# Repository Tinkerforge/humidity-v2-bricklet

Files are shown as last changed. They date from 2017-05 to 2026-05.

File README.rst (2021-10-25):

Humidity Bricklet 2.0
=====================

This repository contains the firmware source code and the hardware design
files. The documentation generator configs can be found at
https://github.com/Tinkerforge/generators

Repository Content
------------------

software/:
 * examples/: Examples for all supported languages
 * build/: Compiled files
 * src/: Source code of firmware
 * Makefile: Makefile to build project

hardware/:
 * Contains KiCad project files and additionally schematics as PDF

datasheets/:
 * Contains datasheets for sensors and complex ICs that are used

Hardware
--------

The hardware is designed with the open source EDA Suite KiCad
(http://www.kicad.org). Before you are able to open the files,
you have to install the Tinkerforge kicad-libraries
(https://github.com/Tinkerforge/kicad-libraries). You can either clone
them directly in hardware/ or clone them in a separate folder and
symlink them into hardware/
(ln -s kicad_path/kicad-libraries project_path/hardware). After that you
can open the .pro file in hardware/ with KiCad and from there view and
modify the schematics and the PCB layout.

Software
--------

If you want to do your own Brick/Bricklet firmware development we highly
recommend that you use our build environment setup script and read the
tutorial (https://www.tinkerforge.com/en/doc/Tutorials/Tutorial_Build_Environment/Tutorial.html).

To compile the C code we recommend you to install the newest GNU Arm Embedded
Toolchain (https://launchpad.net/gcc-arm-embedded/+download).
You also need to install bricklib2 (https://github.com/Tinkerforge/bricklib2).

You can either clone it directly in software/src/ or clone it in a
separate folder and symlink it into software/src/
(ln -s bricklib_path/bricklib2 project_path/software/src/). Finally make sure to
have CMake installed (http://www.cmake.org/cmake/resources/software.html).

After that you can build the firmware by invoking make in software/.
The firmware (.zbin) can then be found in software/build/ and uploaded
with brickv (click button "Flashing" on start screen).

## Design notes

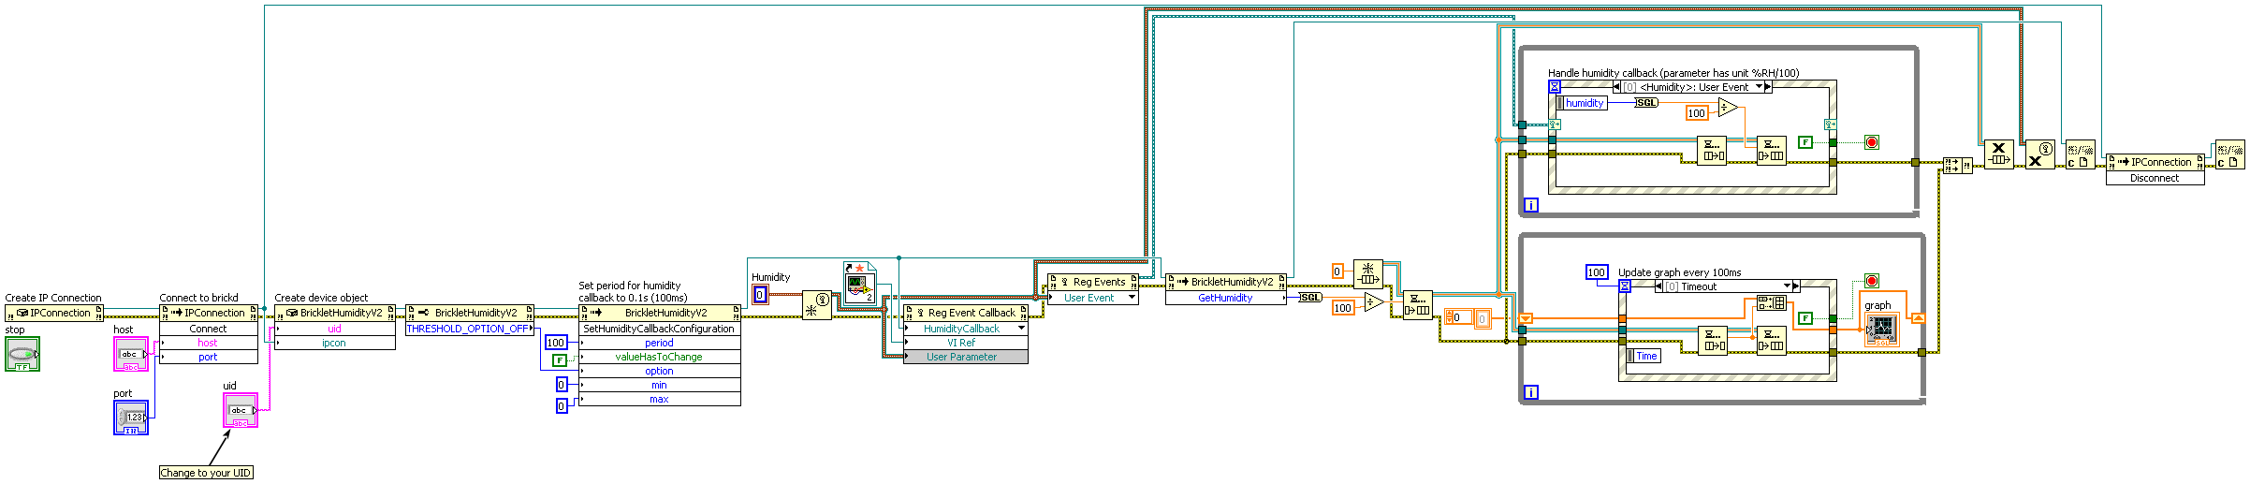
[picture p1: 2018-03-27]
software/examples/labview/Example Graph.vi.png

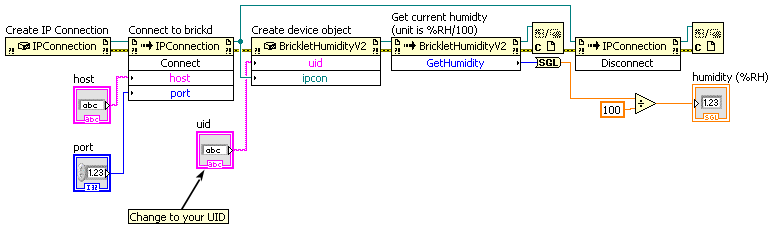
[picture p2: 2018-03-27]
software/examples/labview/Example Simple.vi.png

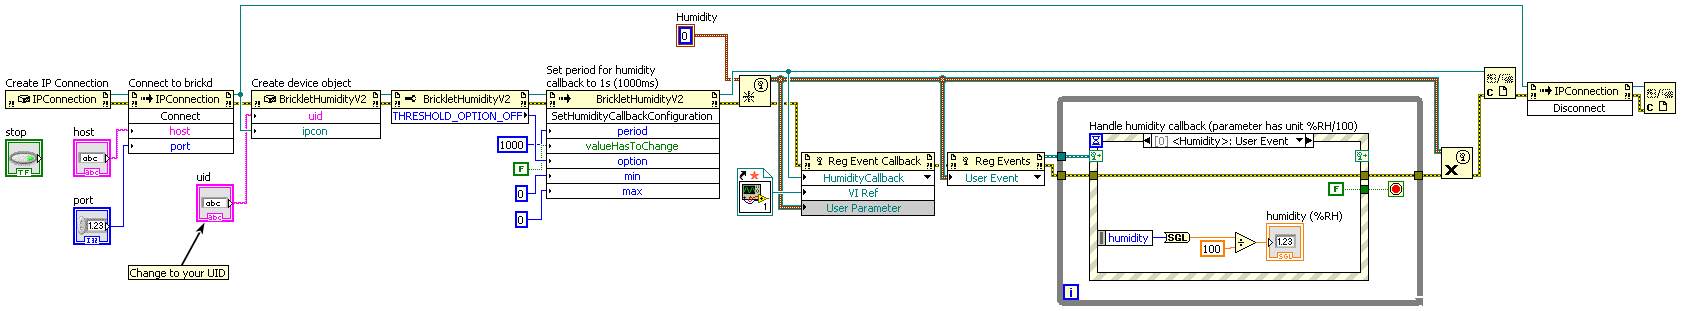
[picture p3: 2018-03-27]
software/examples/labview/Example Callback.vi.png

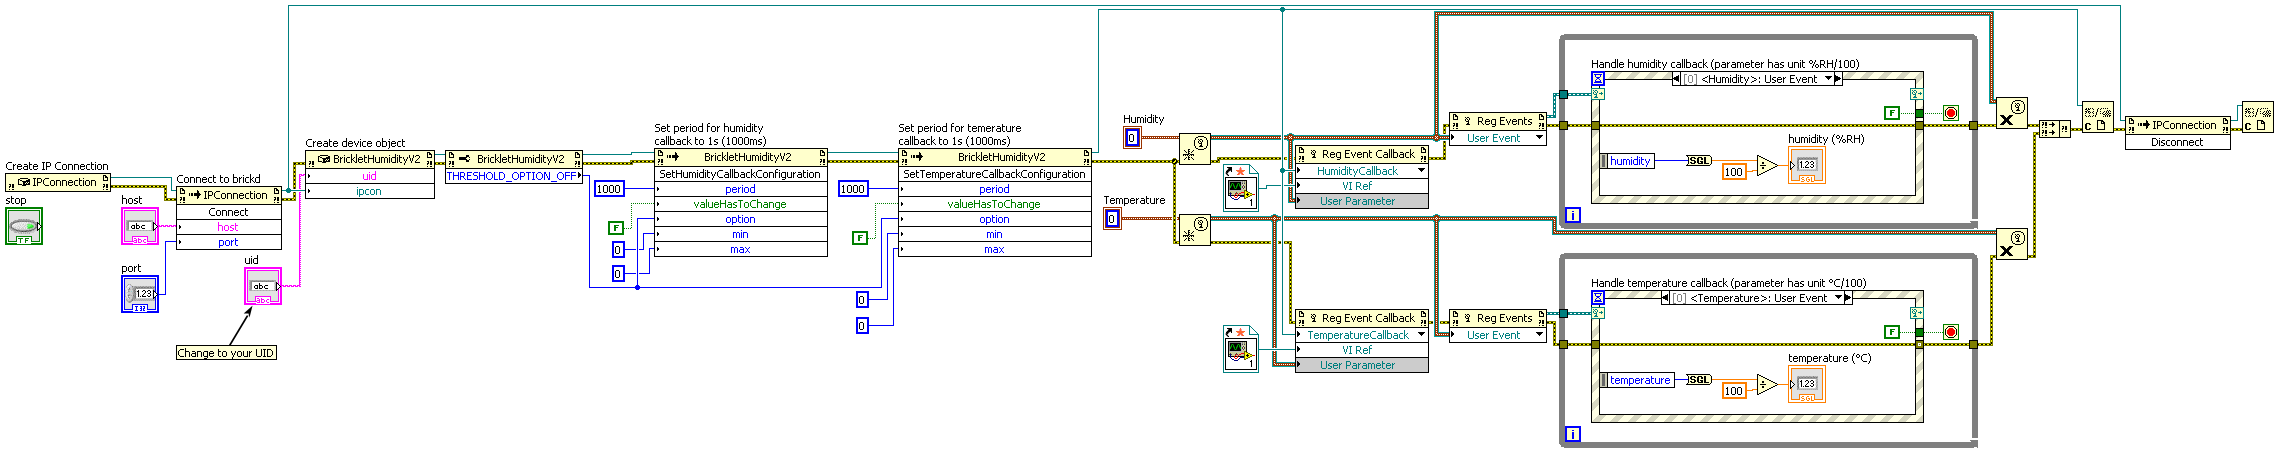
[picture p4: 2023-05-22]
software/examples/labview/Example Callback 2.vi.png

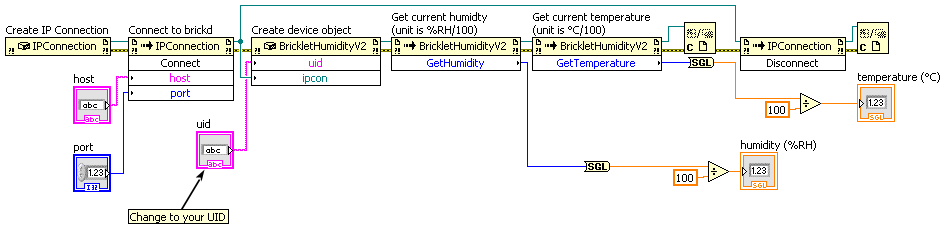
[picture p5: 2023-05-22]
software/examples/labview/Example Simple 2.vi.png

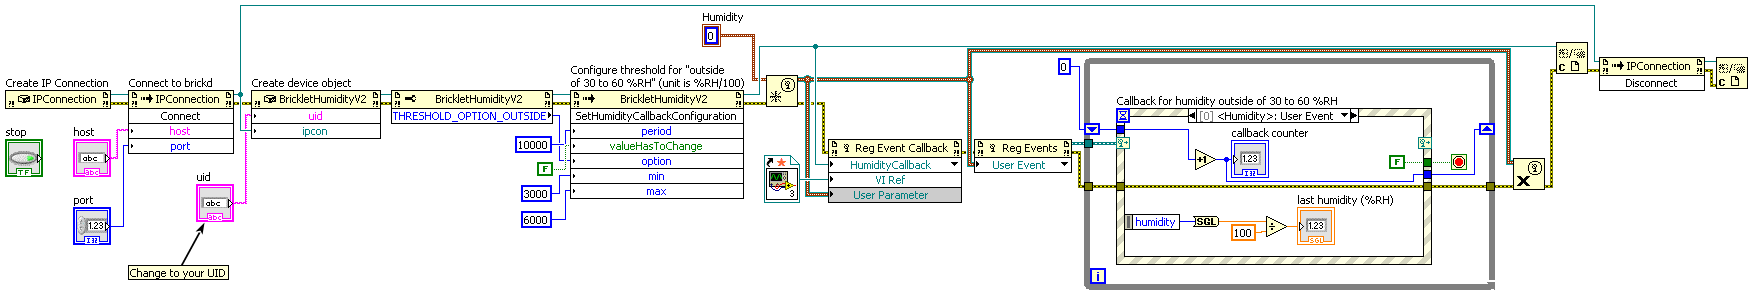
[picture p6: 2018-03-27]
software/examples/labview/Example Threshold.vi.png

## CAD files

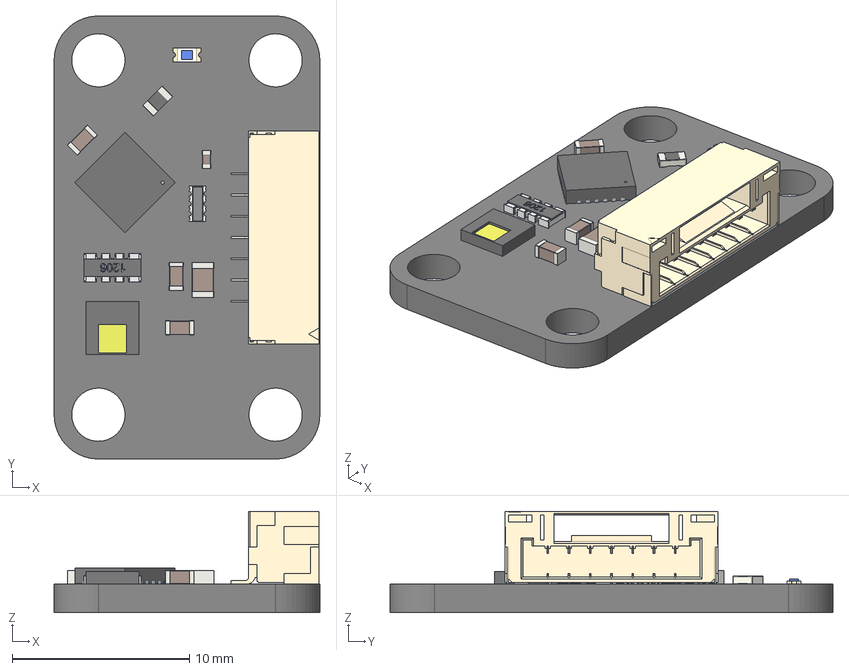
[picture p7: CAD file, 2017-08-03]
hardware/humidity-v2.step
15.0 x 25.0 x 5.70 mm

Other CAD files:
hardware/humidity-v2.FCStd

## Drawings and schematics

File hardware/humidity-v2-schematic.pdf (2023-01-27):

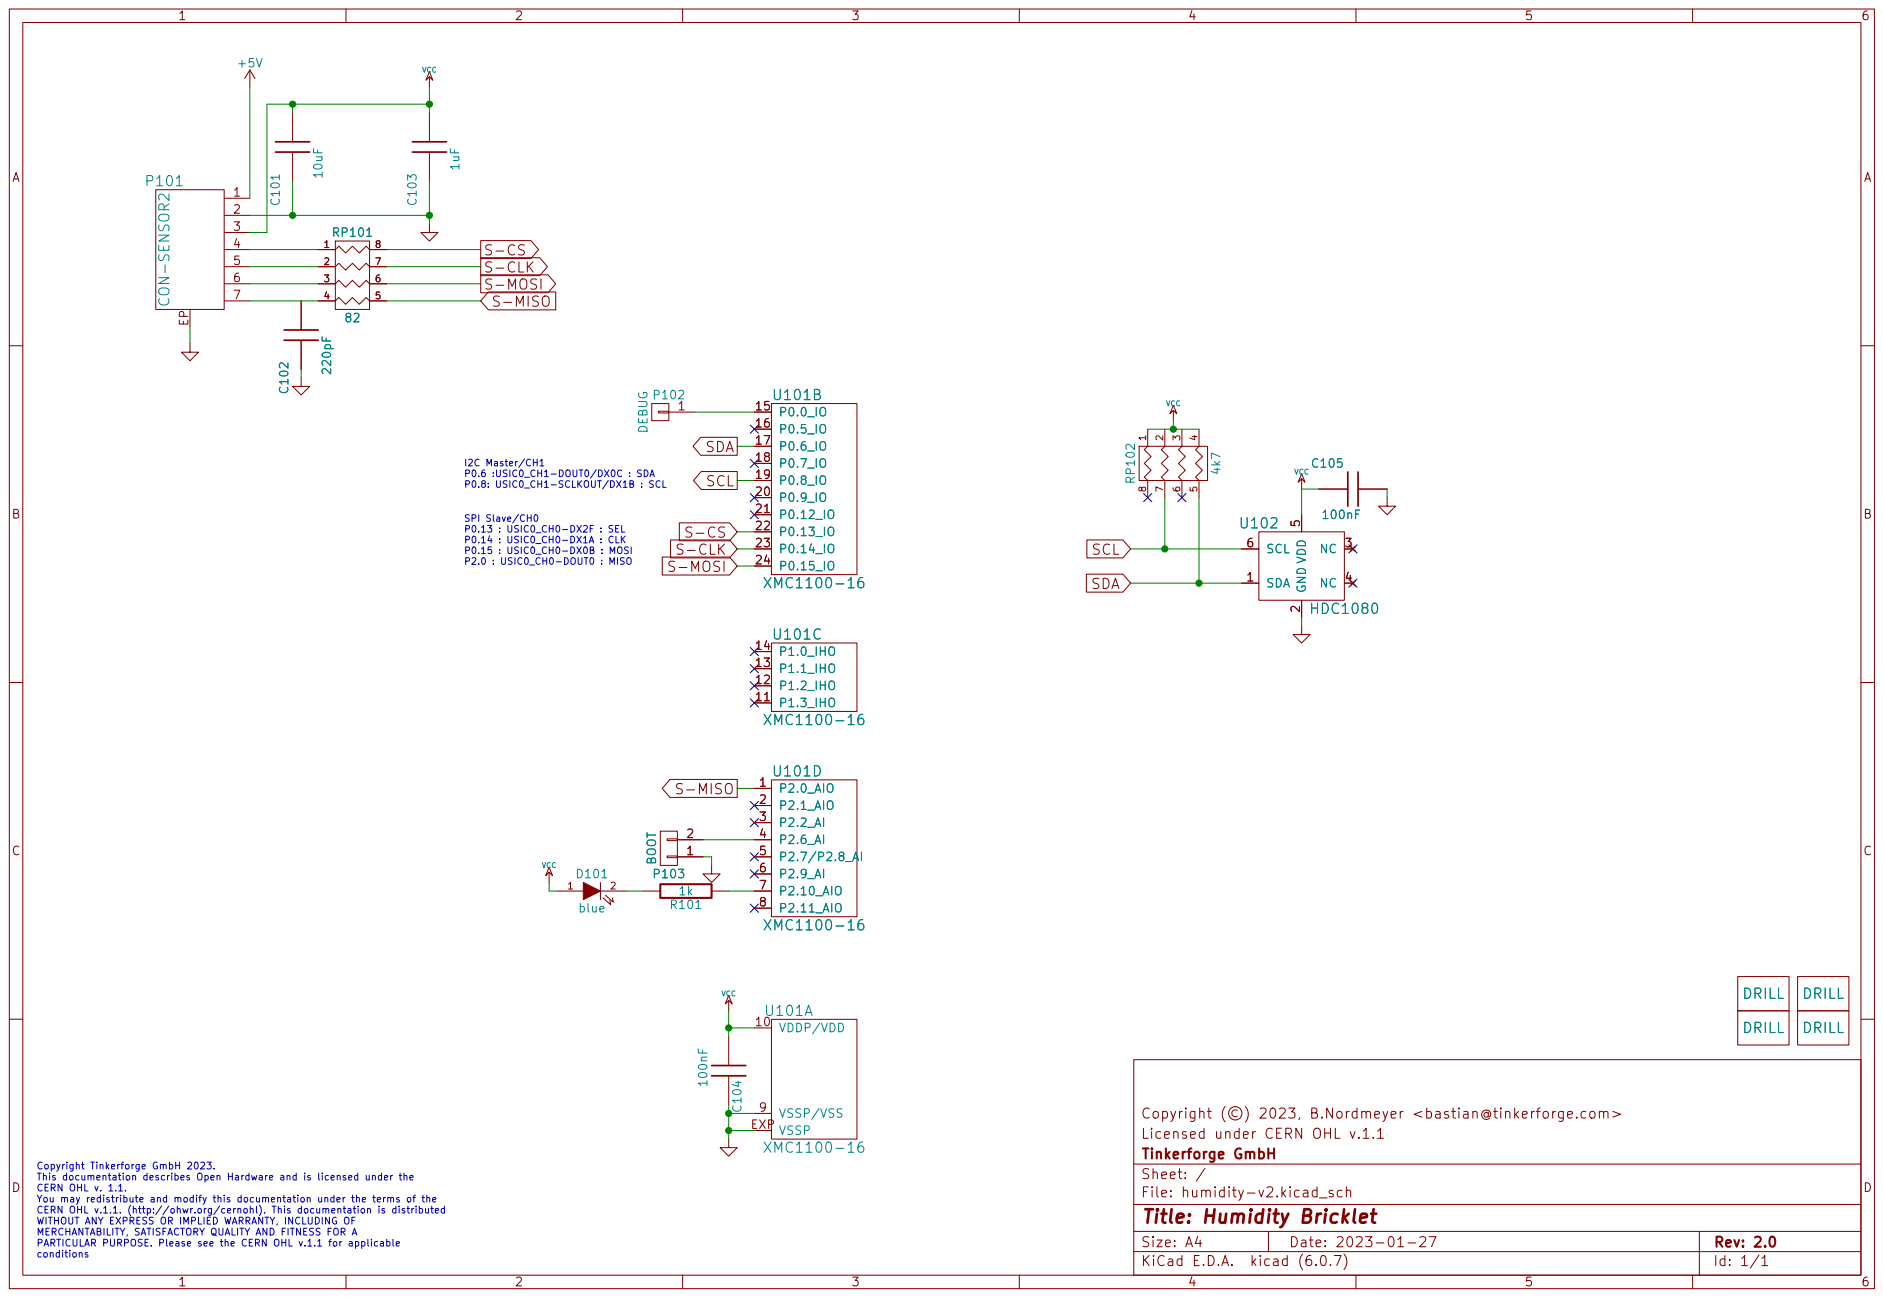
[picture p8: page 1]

P0.8: USIC0_CH1-SCLKOUT/DX1B : SCL SPI Slave/CH0 P0.13 : USIC0_CH0-DX2F : SEL P0.14 : USIC0_CH0-DX1A : CLK

Licensed under CERN OHL v.1.1
File: humidity-v2.kicad_sch Sheet: / Tinkerforge GmbH

Copyright Tinkerforge GmbH 2023. This documentation describes Open Hardware and is licensed under the CERN OHL v. 1.1. You may redistribute and modify this documentation under the terms of the CERN OHL v.1.1. (http://ohwr.org/cernohl). This documentation is distributed WITHOUT ANY EXPRESS OR IMPLIED WARRANTY, INCLUDING OF MERCHANTABILITY, SATISFACTORY QUALITY AND FITNESS FOR A

Id: 1/1 Title: Humidity Bricklet

PARTICULAR PURPOSE. Please see the CERN OHL v.1.1 for applicable
conditions

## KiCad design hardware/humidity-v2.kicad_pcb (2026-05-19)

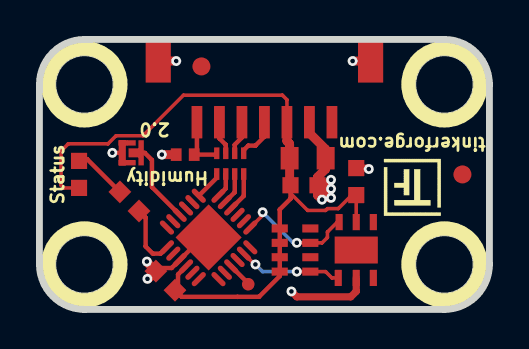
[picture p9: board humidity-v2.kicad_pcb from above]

Board: 2 copper layers, 25.0 x 15.0 mm, 21 parts (1 on the bottom side), 16 nets.

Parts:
C101: 10uF; C0805
C102: 220pF; C0402F
C103: 1uF; C0603F
C104, C105: 100nF; C0603F
D101: blue; D0603F
Fiducial_Mark: VAL**; Fiducial_Mark
Fiducial_Mark#2: VAL**; Fiducial_Mark
P101: CON-SENSOR2
P102: DEBUG; DEBUG_PAD
P103: BOOT; SolderJumper
R101: 1k; R0603F
RP101: 82; 4X0402
RP102: 4k7; 0603X4
U101: XMC1100-16; QFN24-4x4mm-0.5mm
U102: HDC1080; DFN6-30x30_humidity
U103, U104, U105, U106: DRILL; DRILL_NP
VAL: CE_5mm

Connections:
GND: C101.1, C102.1, C103.1, C104.2, C105.2, P101.2, P101.EP, P103.1, U101.9, U101.EXP, U102.2
unnamed: C102.2, P101.7, RP101.4
unnamed: D101.2, R101.2
unnamed: P101.4, RP101.1
unnamed: P101.5, RP101.2
unnamed: P101.6, RP101.3
unnamed: P102.1, U101.15
unnamed: P103.2, U101.4
unnamed: R101.1, U101.7
S-CLK: RP101.7, U101.23
S-CS: RP101.8, U101.22
S-MISO: RP101.5, U101.1
S-MOSI: RP101.6, U101.24
SCL: RP102.7, U101.19, U102.6
SDA: RP102.5, U101.17, U102.1
VCC: C101.2, C103.2, C104.1, C105.1, D101.1, P101.3, RP102.1, RP102.2, RP102.3, RP102.4, U101.10, U102.5

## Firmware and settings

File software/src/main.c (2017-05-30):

/* humidity-v2-bricklet
 * Copyright (C) 2017 Olaf Lüke <olaf@tinkerforge.com>
 *
 * main.c: Initialization for Humidity V2 Bricklet
 *
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
 * You should have received a copy of the GNU Lesser General Public
 * License along with this library; if not, write to the
 * Free Software Foundation, Inc., 59 Temple Place - Suite 330,
 * Boston, MA 02111-1307, USA.
 */

#include <stdio.h>
#include <stdbool.h>

#include "configs/config.h"

#include "bricklib2/bootloader/bootloader.h"
#include "bricklib2/hal/system_timer/system_timer.h"
#include "communication.h"
#include "hdc1080.h"

HDC1080 hdc1080;

int main(void) {
	communication_init();
	hdc1080_init(&hdc1080);

	while(true) {
		bootloader_tick();
		communication_tick();
		hdc1080_tick(&hdc1080);
	}
}

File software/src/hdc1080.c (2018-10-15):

/* humidity-v2-bricklet
 * Copyright (C) 2017-2018 Olaf Lüke <olaf@tinkerforge.com>
 *
 * hdc1080.c: Driver for HDC1080 humidity sensor
 *
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
 * You should have received a copy of the GNU Lesser General Public
 * License along with this library; if not, write to the
 * Free Software Foundation, Inc., 59 Temple Place - Suite 330,
 * Boston, MA 02111-1307, USA.
 */

#include "hdc1080.h"

#include <stdint.h>
#include <stdbool.h>

#include "configs/config_hdc1080.h"
#include "bricklib2/hal/system_timer/system_timer.h"

#include "communication.h"

#include "xmc_i2c.h"
#include "xmc_gpio.h"
#include "xmc_usic.h"

typedef enum XMC_I2C_CH_TDF {
	XMC_I2C_CH_TDF_MASTER_SEND         = 0,
	XMC_I2C_CH_TDF_SLAVE_SEND          = 1 << 8,
	XMC_I2C_CH_TDF_MASTER_RECEIVE_ACK  = 2 << 8,
	XMC_I2C_CH_TDF_MASTER_RECEIVE_NACK = 3 << 8,
	XMC_I2C_CH_TDF_MASTER_START        = 4 << 8,
	XMC_I2C_CH_TDF_MASTER_RESTART      = 5 << 8,
	XMC_I2C_CH_TDF_MASTER_STOP         = 6 << 8
} XMC_I2C_CH_TDF_t;

const uint32_t hdc1080_sps_to_ms[] = {
	50,    // 50 ms    -> 20 SPS
	100,   // 100 ms   -> 10 SPS
	200,   // 200 ms   -> 5 SPS
	1000,  // 1000 ms  -> 1 SPS
	5000,  // 5000 ms  -> 0.2 SPS
	10000, // 10000 ms -> 0.1 SPS
};


// The i2c read/write functions here assume that the FIFO size is never exceeded.
void hdc1080_i2c_write(HDC1080 *hdc1080, const uint8_t reg, const uint16_t length, const uint16_t *data, const bool send_stop) {
	// I2C Master Start
	HDC1080_I2C->IN[0] = (HDC1080_I2C_ADDRESS << 1) | XMC_I2C_CH_TDF_MASTER_START;
	// I2C Send 8 bit register
	HDC1080_I2C->IN[0] = XMC_I2C_CH_TDF_MASTER_SEND | reg;

	// I2C Master send bytes to write
	bool high = true;
	for(uint16_t i = 0; i < length*2; i++) {
		if(high) {
			// Send high byte first
			HDC1080_I2C->IN[0] = XMC_I2C_CH_TDF_MASTER_SEND | (data[i/2] >> 8);
			high = false;
		} else {
			// and low byte second
			HDC1080_I2C->IN[0] = XMC_I2C_CH_TDF_MASTER_SEND | (data[i/2] & 0xFF);
			high = true;
		}
	}

	if(send_stop) {
		// I2C Master stop
		HDC1080_I2C->IN[0] = (uint32_t)XMC_I2C_CH_TDF_MASTER_STOP;
	}
}


void hdc1080_i2c_read(HDC1080 *hdc1080, const uint8_t reg, const uint32_t length) {
	hdc1080_i2c_write(hdc1080, reg, 0, NULL, false);

	// I2C Master restart
	HDC1080_I2C->IN[0] = XMC_I2C_CH_TDF_MASTER_RESTART | XMC_I2C_CH_CMD_READ | (HDC1080_I2C_ADDRESS << 1);

	// I2C Master send ACK/NACK
	if(length != 0) {
		for(uint16_t i = 0; i < length*2-1; i++) {
			HDC1080_I2C->IN[0] = XMC_I2C_CH_TDF_MASTER_RECEIVE_ACK;
		}

		HDC1080_I2C->IN[0] = XMC_I2C_CH_TDF_MASTER_RECEIVE_NACK;
	}

	// I2C Master stop
	HDC1080_I2C->IN[0] = XMC_I2C_CH_TDF_MASTER_STOP;
}

void hdc1080_i2c_read_measurement(HDC1080 *hdc1080, const uint32_t length) {
	// I2C Master start
	HDC1080_I2C->IN[0] = XMC_I2C_CH_TDF_MASTER_START | XMC_I2C_CH_CMD_READ | (HDC1080_I2C_ADDRESS << 1) ;

	// I2C Master send ACK/NACK
	if(length != 0) {
		for(uint16_t i = 0; i < length*2-1; i++) {
			HDC1080_I2C->IN[0] = XMC_I2C_CH_TDF_MASTER_RECEIVE_ACK;
		}

		HDC1080_I2C->IN[0] = XMC_I2C_CH_TDF_MASTER_RECEIVE_NACK;
	}

	// I2C Master stop
	HDC1080_I2C->IN[0] = XMC_I2C_CH_TDF_MASTER_STOP;
}

void hdc1080_change_state(HDC1080 *hdc1080, HDC1080State state) {
	hdc1080->state = state;
	hdc1080->last_state_change = system_timer_get_ms();
}

void hdc1080_init_i2c(HDC1080 *hdc1080) {
	// First de-configure everything, so we can also use
	// this function as i2c reset

	XMC_I2C_CH_Stop(HDC1080_I2C);

	const XMC_GPIO_CONFIG_t config_reset =  {
		.mode             = XMC_GPIO_MODE_INPUT_PULL_UP,
		.input_hysteresis = XMC_GPIO_INPUT_HYSTERESIS_LARGE,
	};

	XMC_GPIO_Init(HDC1080_SDA_PIN, &config_reset);
	XMC_GPIO_Init(HDC1080_SCL_PIN, &config_reset);

	XMC_USIC_CH_TXFIFO_Flush(HDC1080_I2C);
	XMC_USIC_CH_RXFIFO_Flush(HDC1080_I2C);

	WR_REG(HDC1080_I2C->FMR, USIC_CH_FMR_MTDV_Msk, USIC_CH_FMR_MTDV_Pos, 2);

	const XMC_I2C_CH_CONFIG_t master_channel_config = {
		.baudrate = HDC1080_I2C_BAUDRATE,
		.address  = 0
	};

	const XMC_GPIO_CONFIG_t sda_pin_config =  {
		.mode         = HDC1080_SDA_PIN_MODE,
		.output_level = XMC_GPIO_OUTPUT_LEVEL_HIGH,
	};

	const XMC_GPIO_CONFIG_t scl_pin_config = {
		.mode         = HDC1080_SCL_PIN_MODE,
		.output_level = XMC_GPIO_OUTPUT_LEVEL_HIGH,
	};

	XMC_I2C_CH_Init(HDC1080_I2C, &master_channel_config);

	XMC_USIC_CH_SetInputSource(HDC1080_I2C, HDC1080_SDA_INPUT, HDC1080_SDA_SOURCE);
	XMC_USIC_CH_SetInputSource(HDC1080_I2C, HDC1080_SCL_INPUT, HDC1080_SCL_SOURCE);

	XMC_USIC_CH_TXFIFO_Configure(HDC1080_I2C, 48, XMC_USIC_CH_FIFO_SIZE_16WORDS, 0);
	XMC_USIC_CH_RXFIFO_Configure(HDC1080_I2C, 32, XMC_USIC_CH_FIFO_SIZE_16WORDS, 0);

	XMC_I2C_CH_Start(HDC1080_I2C);

	XMC_GPIO_Init(HDC1080_SDA_PIN, &sda_pin_config);
	XMC_GPIO_Init(HDC1080_SCL_PIN, &scl_pin_config);
}
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

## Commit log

2017-05-24 Add initial stub implementation of Humidiy Bricklet 2.0
    [cmake_config_custom.txt]
2017-05-24 Remove unnecessary comment
    The address at that point is used for i2c slave, but we are i2c master.
2017-05-29 Add moving average for humidity/temperature values
2017-07-11 adding hardware files
    [humidity.kicad_pcb, humidity.sch]
2017-08-01 Add 3d information (tbc)
    [humidity.kicad_pcb]
2017-08-03 Add 3d information (final)
    [humidity.kicad_pcb, humidity.sch]
2017-08-03 Add 3d model (*.step & *.FCStd)
    [humidity.FCStd, humidity.step]
2017-08-11 define filter circuit
    [humidity.kicad_pcb, humidity.sch]
2017-09-19 specify processor
    [humidity.kicad_pcb, humidity.sch]
2017-11-06 Add final schematic
2017-11-24 Fix typos in examples
    [example_threshold.c]
2018-02-20 Cleanup KiCad libraries config
    Ensure LibDir=kicad-libraries and LibName1=tinkerforge.
    Remove special library.
2018-05-11 Rename files
    [humidity-v2.FCStd, humidity-v2.kicad_pcb, humidity-v2.sch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]
2018-06-06 fix coordinate origin
    [humidity-v2.kicad_pcb]
2018-06-06 Adapt to bricklib2 callback-value changes to fix wrong length of get-humidity and get-temperature packets
    [communication.h, config.h, hdc1080.c]
2018-06-18 Change capacitor footprint(s) to C0402F
    [humidity-v2.kicad_pcb, humidity-v2.sch]
2018-06-27 Fix "Status" marking
    [humidity-v2.kicad_pcb]
2018-12-14 go: Fix printf parameters.
2019-04-04 Fix bug in GetSamplesPerSecond (was not returning the value)
    [config.h]
2019-04-05 added humidity 2.1 with thermal cutouts
    [humidity-v2.1.kicad_pcb, humidity-v2.1.sch]
2019-04-05 new inverted slot design
    [humidity-v2.1.kicad_pcb, humidity-v2.1.sch]
2019-04-05 new 25x25 design
    [humidity-v2.1.kicad_pcb, humidity-v2.1.sch]
2019-04-08 Fix bug in GetSamplesPerSecond (packet length not set)
    [config.h]
2019-08-22 c: Adapt to bindings changes
    [example_threshold.c]
2020-09-02 uc: Add example driver note.
2020-10-16 uc: Fix divisor type.
    [example_threshold.c]
2021-10-25 Update KiCad link
    https://www.kicad.org/blog/2021/10/Avoid-links-to-former-kicad-domain/
2022-04-27 uc: Adapt to bindings changes
    [example_threshold.c]
2023-01-27 fix schamtic
    [humidity-v2.kicad_pcb, humidity-v2.sch]
2023-01-27 add schematic
    [humidity-v2.kicad_sch]
2023-01-27 Data Cleanup
    [humidity-v2.kicad_pcb, humidity-v2.kicad_sch]
2023-05-22 labview: Add examples that read temperature as well
2026-05-19 update to new kicad version
    [humidity-v2.kicad_pcb, humidity-v2.kicad_sch]

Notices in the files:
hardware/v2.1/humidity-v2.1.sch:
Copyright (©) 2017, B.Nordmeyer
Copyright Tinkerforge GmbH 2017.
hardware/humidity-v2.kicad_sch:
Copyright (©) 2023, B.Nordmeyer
